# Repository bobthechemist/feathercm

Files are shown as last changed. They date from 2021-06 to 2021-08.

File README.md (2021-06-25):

# feathercm
Platform for learning about scientific instrumentation

## Test bed
A test of github desktop and atom integration

## Documentation


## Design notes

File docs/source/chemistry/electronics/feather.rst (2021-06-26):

What is a Feather?
==================

From the `Adafruit <https://www.adafruit.com/category/943>`_ website:

  Feather is a flexible and powerful family of microcontroller main-boards (Feathers) and daughter-boards (Wings) with a wide range of capabilities. They can be plugged into a breadboard for quick prototyping, have built-in battery connectors for your on-the-go projects, and most have built-in lipoly chargers!

We use the Feather platform because it's cheap, powerful and flexible.

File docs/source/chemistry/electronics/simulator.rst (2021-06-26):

Circuit simulator
=================

This circuit simulator can be found at www.falstad.com

.. raw:: html

  <iframe width='100%' height=500 src='https://www.falstad.com/circuit/circuitjs.html' frameborder='0'></iframe>

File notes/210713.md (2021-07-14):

https://book.pythontips.com/en/latest/ternary_operators.html might be an interesting template for book writing on the web.

Noise out of 6004A is fairly significant relative to what's coming from A0.  Adding a 105 cap across the feedback resistor reduces noise with a bit of change in the slope at 2 V.  Upon closer look, adding a cap doesn't improve the noise enough for me to bother, I think.  Might include an open space.

A number of updates to data and echem.  Confirmed that manual iR correction is working.  Can clean up CVs a bit with lowpassfiltering of the data (so post processing).  Added indicator light so user knows when CV scan is complete.  Added command to adjust C2V resistor value.

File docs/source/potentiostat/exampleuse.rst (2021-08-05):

.. _exampleuse:

Current operation
=================

Experimental setup
~~~~~~~~~~~~~~~~~~

Here's an overview of the potentiostat Featherwing,  bob173-beta\ [*]_, connected to an electrochemical cell.

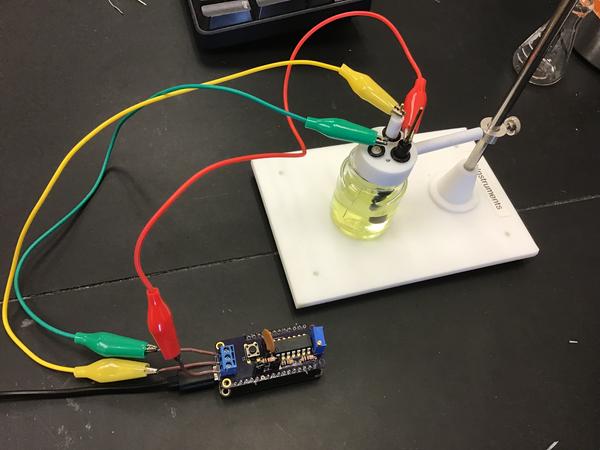
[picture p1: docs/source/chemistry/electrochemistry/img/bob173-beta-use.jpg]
The bob173-beta featherwing potentiostat


Details on the design are provided elsewhere and this page will focus on some example usage.  The setup is a 2 mm Pt disk working electrode with a Pt wire counter and Ag/AgCl reference.  The solution is 4.81 mM potassium ferrocyanide in 0.10 M potassium chloride.  The beta version of the board is pictured; however the gamma version was used for data collection.

Communication via python
~~~~~~~~~~~~~~~~~~~~~~~~

All FeAtHEr-Cm instrumentation will communicate with the user via the serial console interface.  The *easiest* way to do this is with a terminal  program such as `PuTTY <www.putty.org>`_ but the main limitation with that approach is the ease with which experimental data can be transferred.  Therefore, the next best approach is to interact with Python.  In addition to the standard Python installation (I'm using 3.9.6), the serial communication module needs to be installed with `pip install pyserial`.  Then, communication can be streamlined with the (to be documented) module `client.py`.  In a python shell, one would type:

.. code:: python

  >>> import client
  >>> f = client.fc('COM5')
  >>> f.send('get')
  >>> f.read()

The user sends commands using `f.send` and then reads the result using `f.read()`.  It's a primitive strategy at present but the approach will allow for much flexibility, since many systems and programming languages are capable of communicating in this fashion.  The potentiostat understands how to get and set the scan rate, potential limits and sampling frequency.  It also needs to know the value of the resistor in the current to voltage converter.

.. code:: python

  >>> f.send('set SR 0.8')
  >>> f.send('set SP -0.4')
  >>> f.send('set SW 0.6')
  >>> f.send('set EN -0.4')
  >>> f.send('current 9080')
  >>> f.send('go')

The last command tells the potentiostat to perform the cyclic voltammogram.  The user needs to know how long the experiment will take because it is possible to read from the serial buffer before it is populated with the data.  On the gamma version of the board, a red LED is lit when a CV scan is in process.

.. code: python

  >> data = f.read(1)
  >> f.save('myfile.csv', data)

The `1` in the read command above tells the client software to strip text and format numbers for easy export (via `save`) to a CSV file. These CSV files can then be processed the same way you'd process any other data.

Example data
~~~~~~~~~~~~

Figure of example data

  CV of ferrocyanide, 0.5 V/s, 2 mm Pt diameter electrode.  Anodic current is positive. Post processing (low-pass filter) performed in Mathematica.

Above is an example cyclic voltammogram obtained on the bob173-gamma.  The bob173 allows (rather, requires) the end user to manually select an appropriate resistor for the current to voltage conversion.  In this case, the resistor is nominally 2 kOhm, which results in fairly noisy data.  The peak current (~ 80 uA) corresponds to a voltage of 170 mV with this level of amplification, which is roughly 10% of the full scale (+/- 1.65 V) of the potentiostat.

Comparison of current-to-voltage converter setups

  CVs at 0.5 V/s with two separate current-to-voltage resistor values.

As shown above, switching the resistor value in the current-to-voltage converter should have no impact on the overall shape and magnitude of the cyclic voltammogram so long as the resistance does not result in overloading the amplifier.  Switching to a nominally 10 kOhm resistor results in a maximum voltage output of 730 mV.  The noise in the CV with greater amplification is noticeably reduced.  Note that when setting the current value, the measured resistance was used instead of the stated resistance (e.g. 9080 Ohm instead of 10 kOhm).  The resistors used in this setup have a reported tolerance of 5%; therefore, it is important to use the actual resistance.  Nonetheless, it can be seen that the 10 kOhm resistor results in a slightly larger current than the 2 kOhm resistor, suggesting that one (or both) of the resistor values are slightly incorrect.  The percent difference between the two peak currents is 7%.

Various scan rates of ferrocyanide

  Example of cyclic voltammograms from 10 mV/s to 10 V/s.  All voltammograms have been post processed with a low pass filter.

The figure above demonstrates the range of scan rates possible with the bob173-gamma.  After setting the current-to-voltage resistors properly (the lowest value used is 2 kOhm and the largest is 22 kOhm), scan rates between 10 mV/s and 10 V/s can be achieved.  At the highest scan rates, sampling frequency becomes a limiting factor.  The maximum sampling frequency is estimated to be 500 Hz and at 10 V/s with the potential range chosen here, the number of points in the CV is 48.  At the lower end of the scan-rate range, the issue is memory allocation.  Frequently, the low scan-rate scans fail with a memory allocation error.  This issue is likely a bug in the code and the current workaround is to lower the total number of points collected in a single CV scan.

.. note:: The bob173-gamma does have an option for iR compensation; however, it was not tested in this set of data.

Example workup
~~~~~~~~~~~~~~

Standard analysis of electrochemical data (workup) consists of exploring the change in peak current with scan rate, the increase in forward/reverse peak separations with scan rate, and the ratio of forward/reverse peak current as a function of scan rate.  Combined, these three analyses provide a general overview of the electrochemical system and allows for preliminary assignment of electron-transfer mechanisms and rates.

The average of the forward and reverse peak potentials is the :math:`E_{1/2}` relative to the reference electrode used.  This potential should stay constant throughout the range of scan rates employed for a redox system uncomplicated by additional chemical reactions.  The average potential for these data is :math:`0.250 \pm 0.004 V` vs Ag/AgCl which is in reasonable agreement with other reports.\ [*]_

diffusion control plot

  Peak current as a function of the square root of scan rate.  Red line is the best fit line through the data collected at scan rates below 1 V/s.

Above is a plot of the forward (anodic) peak current as a function of scan rate.  At scan rates below 1 V/s, the plot is linear, as expected from theory.  The deviation from linearity at higher scan rates could be due to ohmic drop, but it cannot yet be ruled out that instrumental factors such as sampling frequency and incorrect current-to-voltage settings are contributing factors.  Nonetheless, the lower scan rate data can be fit to the Randles-Sevcik equation in order to extract an estimate of the diffusion coefficient.

.. math::

    i_p = 2.69\times 10^5 n^\frac{3}{2} A C \sqrt{D \nu}

In the equation above, :math:`i_p` is the peak current, n is the number of electrons in the redox process, A is the electrode area in square cm, C is the concentration in mol/mL, D is the diffusion coefficient in cm/s and :math:`\nu` is the scan rate in V/s.  For the ferrocyanide data collected here, the best fit line through the low scan rate data has a slope of :math:`120\ \mu A s^{1/2} V^{-1/2}` which corresponds to a diffusion coefficient of :math:`8.7 \times 10^{-6}\ cm/s`. The reported value for the diffusion coefficient of ferrocyanide in potassium chloride is :math:`6.7 \times 10^{-6}\ cm/s`.\ [*]_ The error is reasonable given that the electrode diameter in this experiment is only known to the nearest mm.  The experimental error (30%) is much larger than what can be attributed to the estimated errors associated with the current-to-voltage conversion (7%) or the lack of temperature control (< 1 %).

The oxidation of potassium ferrocyanide is generally considered fast, and therefore the separation between the forward and reverse peaks should be approximately 59 mV and remain independent of scan rate.\ [*]_ In the figure below, :math:`\Delta E_p` is plotted as a function of scan rate up to 1 V/s.  At very low scan rates, the peak separation is independent of scan rate and approximately 72 mV.  As the scan rate increases, so does the :math:`\Delta E_p` in a non-linear fashion.  It is likely that ohmic losses are playing a role in the peak separation increase.

Analysis of electrochemical reversibility (and resistance)

  Forward/reverse peak separation (:math:`\Delta E_p`) as a function of scan rate.

Lastly, the ratio of the reverse and forward peak currents provides insight into the chemical reversibility of the electron-transfer process.  Both ferro- and ferricyanide are chemically stable under the conditions used in this experiment, so it is expected that the peak current ratio would be close to 1 and independent of scan rate.  Using Nicholson's empirical method for assessing chemical reversibility requires the current at the switching potential.

.. math::

    \frac{i_{rev}}{i_{fwd}} = \frac{i_{rev}}{i_{fwd}} + 0.48 \times \frac{i_{switch}}{i_{fwd}} + 0.086

The peak ratio for the entire scan rate regime investigated here is :math:`0.972 \pm 0.02`, which is expected.  Note that due to the way data are acquired by the bob173, the sampling frequency may "miss" the switching potential.  upon close inspection of the raw data, the recorded data point closest to the switching potential was on average 3 mV less than the target value.

Discussion
~~~~~~~~~~

The results presented here demonstrate the ability to acquire electrochemical data on an ideal redox system with sufficient quality to perform standard analyses such as estimates of the diffusion coefficient and assessment of the chemical and electrochemical reversibility of the redox system.  Post processing of the data is required due to limitations in the analog to digital (ADC) circuitry of the microcontroller used (the M4 Express) as well as the absence of any hardware based noise reduction strategies.  While it would be possibile to eliminate these issues through additional hardware, it would defeat the pedagogical and price-point objectives of the project.  Presently, the bob173-gamma can be created for under $30.  The only additional components not considered in that price are a USB cable and a computer with a USB connection capable of running Python.  A Raspberry Pi computer can be purchased for under $100 (including power and SD card storage but *not* considering keyboard/mouse/monitor peripherals) which is capable of controlling the bob173 via Python as well as perform the post-processing/visualization using Mathematica.  Mathematica is not required for the rudimentary processing and visualization steps, which could also be completed in Python by expanding upon the client.py package.

Additionally, the bob-173 provides some key learning opportunities.  The three main points of understanding are: the design of a voltage divider and the need for buffering; adding signals together using an operational amplifier; and amplifying and converting current from a physical measurement into a voltage that can be read by a computer.  Completion of this module will include lesson plans that explore simulated (via the Falstad online circuit simulator) and hands-on (via the bob173) activities.

client.py
~~~~~~~~~

Here's the module run on the client computer to interface with a FeAtHEr-Cm instrument.

.. code:: python

  import serial
  import csv
  from time import sleep

  class fc():
      def __init__(self, *argv):
          self.s = serial.Serial(argv[0],11500,timeout=1)

      def send(self, cmd):
          self.s.write(f'{cmd}\n\r'.encode('utf-8'))

      def read(self, *argv):
          r = []
          while self.s.in_waiting:
          	r = self.s.readlines()
          if len(argv) > 0:
              r = clean(r)
          return r

      def dia(self, cmd, duration = 1):
          self.send(cmd)
          sleep(duration)
          return self.read()

  def clean(response):
      out = []
      for i in response:
          try:
              out += [ list(map(float,i.strip(b'][\r\n').split(b', '))) ]
          # Silently ignore non-numbers
          except ValueError:
              pass
      return out

  def save(filename, data):
      with open(filename, mode='w', newline='') as f:
          fw = csv.writer(f, delimiter=',')
          for i in data:
              fw.writerow(i)

.. rubric:: Footnotes

.. [*] The name is derived from the first potentiostat that I used as a graduate student at the University of Vermont: the PAR173 by Princeton Applied Research.  While you may think that I've named the Featherwing after myself, it is actually the acronym for Brockport Original Builds.

.. [*] Get this citation.

.. [*] See for example, `<https://www.asdlib.org/onlineArticles/elabware/kuwanaEC_lab/PDF-19-Experiment1.pdf>`_

.. [*] I do not have a good citation for the heterogeneous electron transfer rate of ferrocyanide.

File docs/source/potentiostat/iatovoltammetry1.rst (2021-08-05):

.. _voltagedivider:

The Voltage Divider
===================

In voltammetric measurements, one controls the potential of an electrode immersed in an electrolytic solution containing a redox-active species and observes the current.  In this exercise, you will develop an understanding of how to design an instrument that can perform this experiment.

Let's first look at one approach for setting a potential.  The circuit below is called a *voltage divider* and consists of a voltage source and two resistors.  Notice how the voltage measured in between the two resistors is exactly one half the input voltage of 5 V.

.. raw:: html

  <iframe width='100%' height='500' src='https://tinyurl.com/ygwgal3q' frameborder='0'></iframe>

  Explore this simulation by doing the following:

* Change the values of the resistors and observe how they impact the output voltage.  To make this exercise more manageable, limit your resistor choices so that the *sum* of the resistance remains 2k  (e.g. 500 and 1.5k, 250 and 1.75k).  Determine if the output potential is proportional to the top resistor or the bottom resistor.
* The simulator indicates the flow of current with yellow dots.  Placing the mouse over a component will reveal the current flowing through the object and may provide other information.  Mouse over the voltage source and note the power.  Power is calculated using the equation :math:`P = V \times I` with units of Watts (W).  Determine if the current and power change with changing the resistor values.
* Perform the same exploration but start with resistor values of 10k each.  When adjusting the resistor values, keep the total resistance equal to 20k.  Note similarities and differences in the output voltage, current and power.

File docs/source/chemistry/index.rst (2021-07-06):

The FeAtHEr-Cm Textbook
=======================

Roadmap for version 1.0
~~~~~~~~~~~~~~~~~~~~~~~

Initially, content is not going to be self-standing and will leverage other textbooks that adequately cover theory and pre-requisite material.  Texts such as Skoog's *Principles of Instrumental Analysis* and Harris' *Quantitative Chemical Analysis* are sufficiently ubiquitous that a student will likely have access to one or both of those texts.  Harvey's *Analytical Chemistry 2.1* provides adequate background material on chemical theory and is freely accessible.  These texts will be referenced when background material is necessary.  Rather than reinvent the wheel, there will be little attempt to cover material that is already available in Harvey's text, so once it becomes necessary to introduce content that is presented in one of the "closed" textbooks, the focus will be on expanding on where Harvey lets off.

Building and using a potentiostat
~~~~~~~~~~~~~~~~~~~~~~~~~~~~~~~~~

An instrumental approach to voltammetric measurements will center on the construction of a potentiostat, which requires a basic understanding of circuits involving resistors, capacitors and operational amplifiers.  Circuit analysis at the level of Kirchhoff's voltage/current laws is not necessary and will not be presented.  Coverage of operational amplifiers will be limited to the two ideal principles of op amps (no current draw from the inputs and the voltage difference between the inputs is zero).

The potentiostat used in this course is built with problem-based exploration as a foundational design principle.  Not only are we ignoring important electrical engineering design concepts (which are beyond the scope of this program), but the resulting potentiostat will allow individual components to be probed and analyzed.  For example, the components used to define a virtual ground are also used to introduce the concept of a voltage divider and explore why voltage dividers need to be buffered with an operational amplifer.

Lastly, there is an excellent circuit simulation package available on the internet that is incorporated into the text.  It allows for just-in-time exploration of concepts that are introduced and will allow students to compare actual results to theoretical results.

The expected student trajectory is as follows:

1. Electronics principles

  * Understand what a voltage divider is and how it is created using two resistors
  * Explore relationship between resistor magnitude, power consumed and output voltage
  * Analyze the effect of an external load on a voltage divider
  * Compare simulated and actual performance metrics with the bob173.

2. An overview of operational amplifiers and their utility

  * Understand that an operational amplifier can compare the relative values of the input voltages
  * Explore the role of op amps in buffering an input
  * Evaluate how performance of a real operation amplifier compares to the ideal behavior of drawing no current.
    - This section will likely be the first entry into (circuit) python programming.
  * Explore how operational amplifiers can add multiple inputs together.
  * Explore how operational amplifiers can magnify the intensity of a signal.

3. Combining the elements - a basic adder potentiostat

  * Learn how to read a schematic
  * Explore python programming needed to communicate with the bob173
  * Calibrate voltage and current scales of the bob173
  * Perform a cyclic voltammetry experiment and analyze results

4. Going further - improving the potentiostat

  * Reducing noise
  * Incorporating iR compensation
  * Exploring instrument limitations
  * Exploring a "new" chemical system.

Building a colorimeter
~~~~~~~~~~~~~~~~~~~~~~

One of the most prevalent instrument design activities is the construction of a rudimentary spectrometer.  Rather than provide yet another example, the proposed instrument design activities will focus on several under-represented concepts:

* Exploring how an instrument controls/operates a source and records information from a detector
* Analyze non-idealities due to instrument design (a primary example is stray light)
* Investigating signal transduction for novel data acquisition strategies (one example might be transducing detector response to an audio signal)

One design idea is to intentionally incorporate source flicker into the instrument.  Then create a system that provides dual-beam capabilities and explore how effective this approach is at reducing such noise.

Concepts covered in this module will include electronics (transimpedance amplifiers), programming (digital and analog IO), deviations from Beer's Law and signal transduction.  It may also be an interesting segue into 3D printing design.

Building a thermal conductivity detector
~~~~~~~~~~~~~~~~~~~~~~~~~~~~~~~~~~~~~~~~

Prior to exploring chromatography instrumentation, we need to have a reasonable detector.  It is possible that one could use concepts in the previous sections (spectroscopy, voltammetry) to design a detector, and that could/should be part of a future direction.  Here we are interested in exploring a detector that is often described in instrumental analysis courses, the thermal conductivity detector.  Designing and testing the detector will provide an opportunity to further develop our electronics understanding through the development of a Wheatstone bridge.  The goal would be to develop an instrument that can, for example, analyze a binary gas sample.  The approach we are revisiting was first described in J. Chem Ed. 28, 576 (1951) and it is time we revisit this approach.

Creating a rudimentary Gas Chromatograph
~~~~~~~~~~~~~~~~~~~~~~~~~~~~~~~~~~~~~~~~

The previous module presented an approach to analyzing gaseous mixtures, which suggests that by adding a means to separate mixtures prior to TCD analysis should result in a functioning GC.  There are DIY GC designs on the internet that use packed columns (one of them actually uses kitty litter) which might be sufficient to perform alcohol separations.

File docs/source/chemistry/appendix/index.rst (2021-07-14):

Appendix
========

Various topics for just in time learning

* microcontroller basics
* essentials of resistor circuits
* python basics
* [Do][Explore][Act]
* Contributing
*

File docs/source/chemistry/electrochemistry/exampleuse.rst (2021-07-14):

Current operation
=================

Experimental setup
~~~~~~~~~~~~~~~~~~

Here's an overview of the potentiostat Featherwing,  bob173-beta[*]_, connected to an electrochemical cell.

The bob173-beta featherwing potentiostat

Details on the design are provided elsewhere and this page will focus on some example usage.  The setup is a 2 mm Pt disk working electrode with a Pt wire counter and Ag/AgCl reference.  The solution is ~ 10 mM potassium ferrocyanide in 0.1 M potassium nitrate.

Communication via python
~~~~~~~~~~~~~~~~~~~~~~~~

All FeAtHEr-Cm instrumentation will communicate with the user via the serial console interface.  The *easiest* way to do this is with a terminal  program such as `PuTTY <www.putty.org>`_ but the main limitation with that approach is the ease with which experimental data can be transferred.  Therefore, the next best approach is to interact with Python.  In addition to the standard Python installation (I'm using 3.9.6), the serial communication module needs to be installed with `pip install pyserial`.  Then, communication can be streamlined with the (to be documented) module `client.py`.  In a python shell, one would type:

.. code:: python

  >>> import client
  >>> f = client.fc('COM5')
  >>> f.send('get')
  >>> f.read()

The user sends commands using `f.send` and then reads the result using `f.read()`.  It's a primitive strategy at present.  The potentiostat understands how to get and set the scan rate, potential limits and sampling frequency.

.. code:: python

  >>> f.send('set SR 0.8')
  >>> f.send('set SP -0.4')
  >>> f.send('set SW 0.6')
  >>> f.send('set EN -0.4')
  >>> f.send('go')

The last command tells the potentiostat to perform the cyclic voltammogram.  The user needs to know how long the experiment will take because it is possible to read from the serial buffer before it is populated with the data.

.. code: python

  >> data = f.read(1)
  >> f.save('myfile.csv', data)

The `1` in the read command above tells the client software to strip text and format numbers for easy export (via `save`) to a CSV file. These CSV files can then be processed the same way you'd process any other data.

Example data
~~~~~~~~~~~~

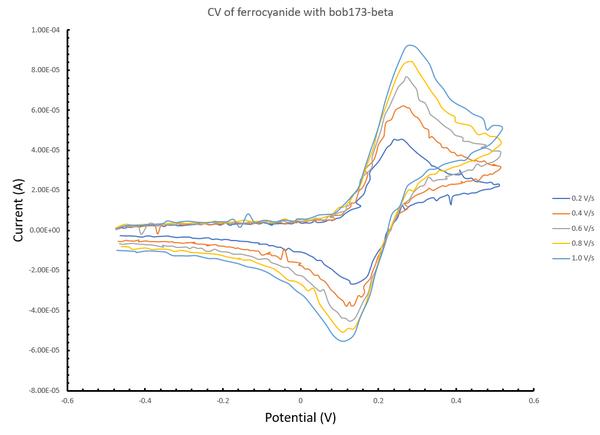
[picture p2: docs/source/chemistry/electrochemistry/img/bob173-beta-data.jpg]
Figure of example data


Above is a collection of cyclic voltammograms obtained on the bob173-beta.  The solution contains ferrocyanide and the data are plotted such that positive potentials are to the right and anodic current is positive[*]_. The scan rates range from 0.2 to 1.0 V/s and show the expected increase in current with increasing scan rate.  There is a fair amount of noise in the voltammograms.  The current amplification resistor in this version of the potentiostat is 15 kOhm which is appropriate for currents in the upper 10s of microamps.  Thus, I would expect decreased noise with a better choice of amplification resistor.  Further, there is no attempt to shield the potentiostat from EMF, which will likely also contribute noise.

Example workup
~~~~~~~~~~~~~~

A limited amount of analysis can be done at this stage.  First, one can confirm that the electrochemical process is diffusion controlled by plotting peak current as a function of the square root of scan rate.  The plot is reasonably linear with nonlinearities likely due to the aforementioned noise and to a lesser extent some issues with uncompensated resistance.  An important next step is to repeat this experiment with precise concentrations in order to verify that the diffusion coefficient estimated from these data is consistent with literature values.

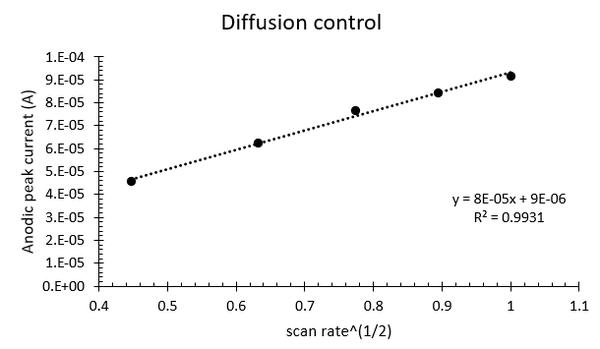
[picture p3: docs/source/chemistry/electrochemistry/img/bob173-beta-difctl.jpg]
Analysis of diffusion control


Chemical and electrochemical reversibility can be assessed by investigating the peak potentials and their currents.  Since the oxidation product, ferricyanide, is stable, it is expected that the ratio of the reverse to forward peak currents is close to one.  As calculated using the Nicholson equation, the ratio ranges from 0.91 to 0.95, which is a reasonable agreement given the rudimentary nature of the potentiostat.  Electrochemical reversibility is assessed by measuring the difference in peak potentials, as shown in the figure below.

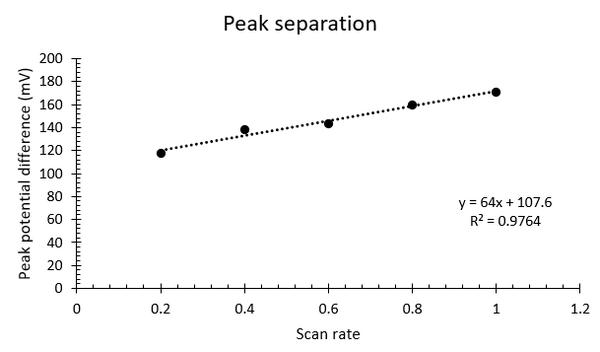
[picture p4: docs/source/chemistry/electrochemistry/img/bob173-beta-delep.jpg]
Analysis of electrochemical reversibility (and resistance)


At the slowest scan rates, the peak separation is approximately 120 mV, which is very large for this system and is likely influenced by uncompensated resistance.  The beta version of the potentiostat does not provide compensation.  While it is possible to incorporate the feature into a future design, it will be of limited use with the current platform since the microcontroller can only provide +/- 1.65 V and therefore will provide very little compliance.  That said, it is possible to improve the performance by using higher electrolyte concentrations and smaller electrodes.

Directions
~~~~~~~~~~

With this proof of concept data, we demonstrate that it is possible to perform electrochemical measurements with the bob173-beta featherwing.  The first area of improvement will be optimizing the current amplification stage and isolating the potentiostat from external interference.

client.py
~~~~~~~~~

Here's the module run on the client computer to interface with a FeAtHEr-Cm instrument.

.. code:: python

  import serial
  import csv
  from time import sleep

  class fc():
      def __init__(self, *argv):
          self.s = serial.Serial(argv[0],11500,timeout=1)

      def send(self, cmd):
          self.s.write(f'{cmd}\n\r'.encode('utf-8'))

      def read(self, *argv):
          r = []
          while self.s.in_waiting:
          	r = self.s.readlines()
          if len(argv) > 0:
              r = clean(r)
          return r

      def dia(self, cmd, duration = 1):
          self.send(cmd)
          sleep(duration)
          return self.read()

  def clean(response):
      out = []
      for i in response:
          try:
              out += [ list(map(float,i.strip(b'][\r\n').split(b', '))) ]
          # Silently ignore non-numbers
          except ValueError:
              pass
      return out

  def save(filename, data):
      with open(filename, mode='w', newline='') as f:
          fw = csv.writer(f, delimiter=',')
          for i in data:
              fw.writerow(i)

.. [*] The name is derived from the first potentiostat that I used as a graduate student at the University of Vermont: the PAR173 by Princeton Applied Research.  While you may think that I've named the Featherwing after myself, it is actually the acronym for Brockport Original Builds.
.. [*] Sorry Bill.

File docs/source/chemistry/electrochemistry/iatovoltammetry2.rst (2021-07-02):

Voltage Divider Problems
========================

.. note::

  In the last section, you should have noticed that the output voltage varies proportionally with the lower resistor and that the current and power are dependent on the sum of the two resistors. The equation for determining the output voltage is :math:`V_{out}=V_{in}\frac{R_{lower}}{R_{lower}+R_{upper}}`

One way we could create a variable potential is by changing the resistance values.  A variable resistor, or *potentiometer* provides this functionality.  The circuit below is similar to the one on the previous page, with several important differences:

* The two resistors are replaced by a potentiometer, which makes it easy to adjust the resistances above and below the test point while keeping the total resistance the same.  You should see a slider on the right hand side of the simulator that will control the potentiometer position.
* A switch has been added, which can be opened and closed with a double click.
* A new resistor has been added, which is the *load* or the object that we want to apply the output voltage to.

.. raw:: html

  <iframe width='100%' height='500' src='https://tinyurl.com/yfeq6ato' frameborder='0'></iframe>

Explore this simulation by doing the following:

* Make sure the switch is open.  Adjust the potentiometer so that the resistances are roughly equal and the output voltage is about 2.5 V.
* Close the switch and note how the output voltage is affected.  Collect several data points with varying the resistance and noting the lower resistor value, the output potential with the switch open and the output potential with the switch closed.

.. note::

  Notice how the load is in parallel with the lower resistor.  Since resistors in parallel add as inverses (:math:`\frac{1}{R_{total}}=\frac{1}{R_a}+\frac{1}{R_b}`), the load strongly impacts the performance of the voltage divider.  The load resistance must be much higher than the resistors used in the voltage divider in order to minimize this impact.

  However, using too small of a resistor for the voltage divider will result in excessive power usage.  One cannot optimize both low power consumption and load resistance tolerance.

Problems
~~~~~~~~

#. For a voltage divider with a total resistance of 2 kOhm, what is the minimum load resistance that will have a small (< 5%) impact on the desired output voltage?  (Assume for this exercise that Vout is 1/2 Vmax.)
#. Perform the same calculation for a 20 kOhm voltage divider.
#. Does the R95 (my term) change with changing the desired output voltage?

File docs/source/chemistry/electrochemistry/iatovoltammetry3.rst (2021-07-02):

An operational amplifier primer
===============================

.. note::

  We saw in the last section that the load we are trying to work with impacts the performance of a resistor-based voltage divider.  Ideally, we need to isolate the voltage divider from the load.  In this section we will learn how a component called an *operational amplifier* can perform that task.

Just the facts
~~~~~~~~~~~~~~

As this material is designed for chemists who need to know (or want to know) some useful electronics, we will skip a lot of the theory behind operational amplifiers and focus on the two important features that make them useful and then move on to several basic configurations that are found frequently in scientific instrumentation.

An operational amplifier is an active component that amplifies weak signals.  It has two inputs (a non-inverting input designated **+** and an inverting input designated **-**) and one output.  The symbol used for operational amplifiers in schematics is a triangle.

.. raw:: html

  <iframe width='100%' height='500' src='https://tinyurl.com/ydptekz5' frameborder='0'></iframe>

Note that in the diagram above, a square wave pulse with amplitude +/- 5 V is applied to the inverting input and the non-inverting input is tied to ground.  Try the following explorations:

* Describe the output in relation to the input
* Mouse over the oscilloscope trace to find the amplitude of the output signal.  Where does this value come from? (Hint: right click on the op amp and select properties.)
* Reconfigure the inputs so that the output signal is in phase with the input signal.

In this circuit, the op amp is behaving as a *comparator*.  It is comparing the two inputs and responding with the following result

* If the inverting input is greater than the non-inverting input (which is tied to ground) then set the output as negative as possible.
* If the inverting input is less than the non-inverting input, then set the output as positive as possible.

A comparator does one more thing, which isn't readily apparent in the simulation: if the inputs are equal, set the output to zero.

.. note::

  You should be able to give this a try by deleting the ground and adding a wire from the square wave source to the non-inverting input.

Two important points
~~~~~~~~~~~~~~~~~~~~

We'll quickly see that op amps can do much more than just compare the values of their inputs.  As we explore some other configurations, there are two important rules that we must keep in mind:

1. An operational amplifier does everything in its power to make the *difference* between voltages at the inverting and non-inverting inputs be zero.
2. In an ideal operational amplifier, the inputs do not draw any current.

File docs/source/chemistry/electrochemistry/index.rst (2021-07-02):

Instrumental Approach to Voltammetry
====================================

In this three week module, you will learn about the electrochemical method called *cyclic voltammetry* by building an instrument that performs the technique: a *potentiostat*.  We are going to use an *instrumental approach* whereby the focus will be on how to create an instrument that does the experiment we want to perform.

.. toctree::
  :maxdepth: 2
  :hidden:

  iatovoltammetry1
  iatovoltammetry2
  iatovoltammetry3
  echempt1

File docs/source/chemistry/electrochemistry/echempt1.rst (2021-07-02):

A review of Voltammetry fundamentals
====================================

Much of this section is paraphrased from `David Harvey's Analytical Chemistry 2.1 text <https://chem.libretexts.org/Bookshelves/Analytical_Chemistry/Book%3A_Analytical_Chemistry_2.1_(Harvey)/11%3A_Electrochemical_Methods>`_ which can be accessed via Libre Text.

.. seealso:: Be sure to check out section 11.1 of Harvey's book for a refresher on these topics. 

Electrochemical techniques rely on the measurement of potential and current in order to understand chemical phenomena such as reactivity and concentration.  Most, but not all, electrochemical techniques involve the study of the movement of electrons in an oxidation-reduction reaction.  There are several important concepts in electrochemistry which are worth reviewing:

#. we cannot control simultaneously current and potential
#. the electrode's potential determines the analyte's form at the electrode's surface
#. the concentration of analyte at the electrode's surface may not be the same as its concentration in bulk solution
#. current is a measure of the rate of the analyte's oxidation or reduction
#. in addition to an oxidation-reduction reaction, the analyte may participate in other chemical reactions

Let's discuss how these five concepts are incorporated into voltammetry.  The first item suggests that we must choose whether to control potential or current.  As the name suggests, we *measure* the current (-ammetry) as a function of potential in a voltammetric measurement. Because we control the potential, we control what is happening at the electrode surface.  We can adjust the potential to force a species in solution [#]_ to become oxidized or reduced by adjusting the potential relative to the reduction potential of the solute.  Note that we only have control of what happens *at the electrode/electrolyte interface*.  The bulk of the solution is unaffected unless we have specifically designed the experiment to influence the entire solution.  The fact that electrochemical reactions are happening *heterogeneously* in the solution has a significant impact on the relationships between current and potential that we will observe.  The last two points are what make voltammetry interesting.  Since current is a measure of the flow of electrons, more electron flow indicates that more oxidation or reduction (collectively, electrolysis) is happening.  Therefore, the magnitude of the current informs us about the rate of a reaction.  Lastly, we can use voltammetry to explore what - if anything - a molecule does before or after electrolysis.

.. rubric:: Footnotes

.. [#] technically, or adsorbed onto the electrode surface, but we won't deal with adsorbed species here.

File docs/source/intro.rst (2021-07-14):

Start Here
==========

**Welcome**. If you are here, you were either invited or spend an awful lot of time randomly clicking links on the internet...

``FeAtHEr-Cm`` is a platform for building a better understanding of scientific instrumentation.  It is my attempt at developing what I call an *Instrumental Approach to Chemical Analysis.*\ [*]_  Traditionally, the second semester of analytical chemistry covers instrumentation used in the discipline.  Recent advances in technology, electronics and programming allow us to explore how scientific measurements are made by *designing our own instruments* and using them to explore chemical systems.  FeAtHEr-Cm helps us do that.

Why FeAtHEr-Cm?
~~~~~~~~~~~~~~~

When exploring platforms that could be useful for introducing chemists it scientific instrumentation design, I wanted something that was relatively inexpensive, easy to operate, established, and supported by a larger community.  The `feather platform <https://learn.adafruit.com/adafruit-feather>`_ by Adafruit Industries checks all of those boxes *plus* provides a cross-compatible platform with a vast array of tools already available.  The flexibility comes at a cost, however, and that is the array of choices that can be made is a bit overwhelming.  To bring some focus to the project, I have made two design decisions:

* The microcontroller board that will serve as the brains of any FeAtHEr-Cm instrument is the M4 Express and there is no intention to make activities compatible with other microcontrollers.
* All programming will be done in `Circuit Python <circuitpython.org>`_

The primary reason for selecting the M4 is that this microcontroller contains two 12-bit digital-to-analog outputs, which simplifies many designs (not least of which is the potentiostat).  The analog inputs are also 12 bit which is a very nice feature in education-based instrumentation.  By limiting software design to circuit python we not only decrease the programming learning curve (only one language is needed to control and communicate with the instrument) but it increases the accessibility of the instrument by being a plug and play option.  Note that a big downside to the M4 is that the analog to digital converter (ADC) isn't as good as it needs to be, which is why *the instrument you build is not suitable for research applications*.  There are tweaks made (and being made) to address the problems so that the potentiostat remains easy to build and configure while still serving as a meaningful learning platform.

As for that odd capitalization, it is something I've done for a long time.  I'm not alone and there are `many chemists <https://www.ionicviper.org/>`_ who do this.

Want to dive in?
****************

If you are excited about this project and want to start exploring right away, then I suggest purchasing an `M4 Feather <https://www.adafruit.com/product/3857>`_  along with Adafruit's `parts pal <https://www.adafruit.com/product/2975>`_.  That will give you nearly all the parts you need, and many that you'll find fun to play with.  The only additional components I suggest would be alligator clips and a quad op amp - the MCP6004 - which isn't sold by Adafruit but you can find it at other vendors.  I purchase from `Newark <newark.com>`_ but you might want to try `Digikey <digikey.com>`_ as they are also a reseller for Adafruit products and you might be able to get all of the components from one vendor.

A work in progress
~~~~~~~~~~~~~~~~~~

This project is in the very early stages of development.  If you are visiting, you will likely find links that do not work, documentation that seems to require a significant amount of prerequisite knowledge, and many, many outlines and placeholders.  My intention for a *version 1.0* of this project is an instrument with activities for each of the three main areas of chemical instrumentation (spectroscopy, electrochemistry and chromatography).  I am currently working on the electrochemistry modules.

An open, collaborative effort
~~~~~~~~~~~~~~~~~~~~~~~~~~~~~

I am building this project using `github <github.com>`_ and `read the docs <readthedocs.com>`_ for a few important reasons.

* Both platforms provide open access to the content, so that others may view, use and modify what is presented here
* Both platforms work nicely together, allowing me to generate both software and instructional content in one location and have it display in a pretty format without much input on my part.
* This approach allows community members to contribute to the project either as content generators or content reviewers.

I imagine that users of the content will find typographical and content errors and wish to propose corrections; others may have suggestions on how to better present content.  With Github, those users should be able to make those requests in a documented, public fashion.  If the changes are accepted, they get pushed immediately to the project.

What to explore right now
~~~~~~~~~~~~~~~~~~~~~~~~~

The current area of activity is building the potentiostat, creating software for controlling it and developing activities for exploring how a potentiostat is built and operated.  You will likely see the most changes in these pages over the next few weeks.

.. [*] Yes, this title is homage to Ewing's 1954 text and no, it is not at all suggestive that I am (or ever will be) comparable to Ewing as a scientist.

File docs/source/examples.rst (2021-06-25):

Examples
========

Installation/Usage:
*******************
I'll get there eventually

Some other example
******************
:math:`\alpha > \beta`

.. math::

    n_{\mathrm{offset}} = \sum_{k=0}^{N-1} s_k n_k

    \ce{H2O -> H2 + O2}

.. seealso:: this is a simple **seealso** note.

.. note:: This is a **note** box.

.. warning:: this is a warning to you.

.. sidebar:: Sidebar Title
    :subtitle: Optional Sidebar Subtitle

    Subsequent indented lines comprise
    the body of the sidebar, and are
    interpreted as body elements.

Really cool embed
*****************

Wouldn't it be nice if you could embed code for dynamic web-based textbooks?

.. raw:: html

  <iframe width='100%' height='300' src='https://rdrr.io/snippets/embed/' frameborder='0'></iframe>

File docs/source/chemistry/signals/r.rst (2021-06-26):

Try R here
==========

R is a scripting language designed to facilitate data processing and analysis. On this page, you can try writing R code.  Note that this page uses `rdrr <https://rdrr.io>`_ to interpret commands.  This service is provided for free and queuing a large class might take a while.

.. raw:: html

  <iframe width='100%' height='500' src='https://rdrr.io/snippets/embed/' frameborder='0'></iframe>

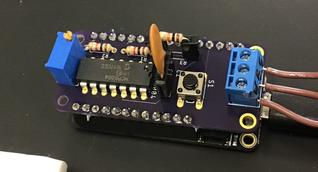
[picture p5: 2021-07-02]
docs/source/chemistry/electrochemistry/img/bob173-beta.jpg

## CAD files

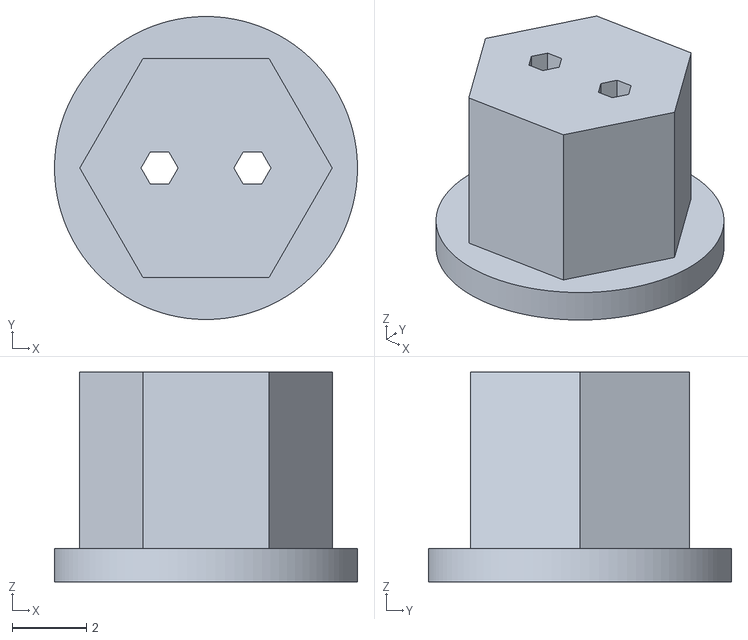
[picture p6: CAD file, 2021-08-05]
design/spectroscopy/turbidity-led-cap.stl
8.16 x 8.16 x 5.65

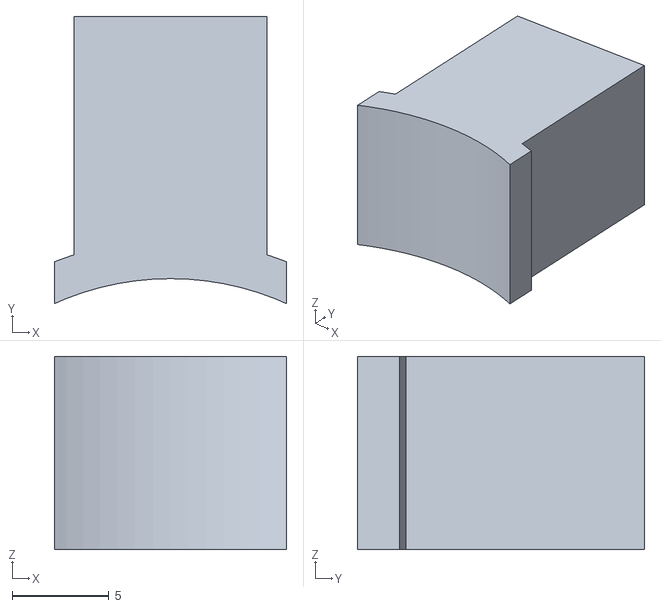
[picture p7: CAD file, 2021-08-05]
design/spectroscopy/turbidity-light-block.stl
12.0 x 14.9 x 10.0

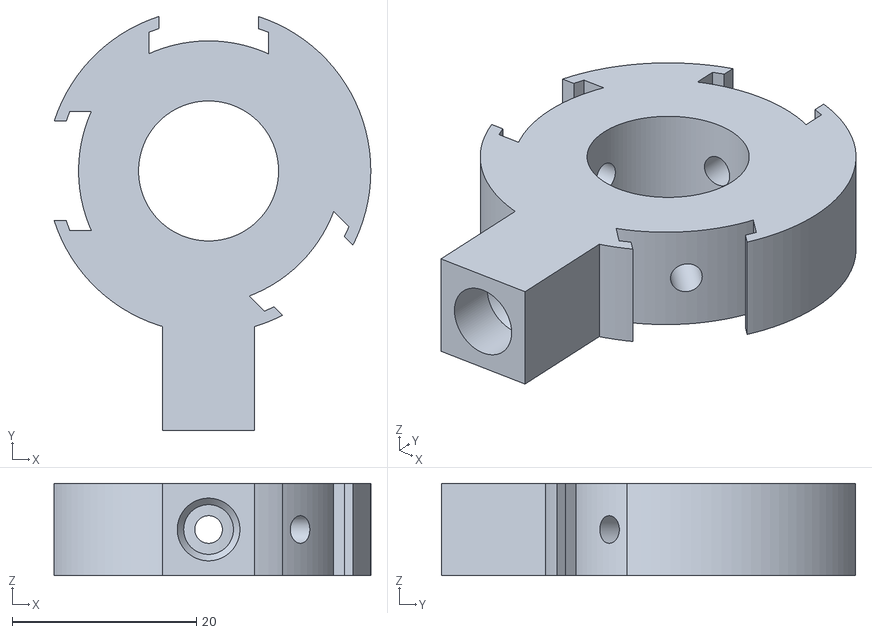
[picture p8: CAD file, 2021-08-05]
design/spectroscopy/turbidity-base.stl
34.4 x 45.0 x 10.0

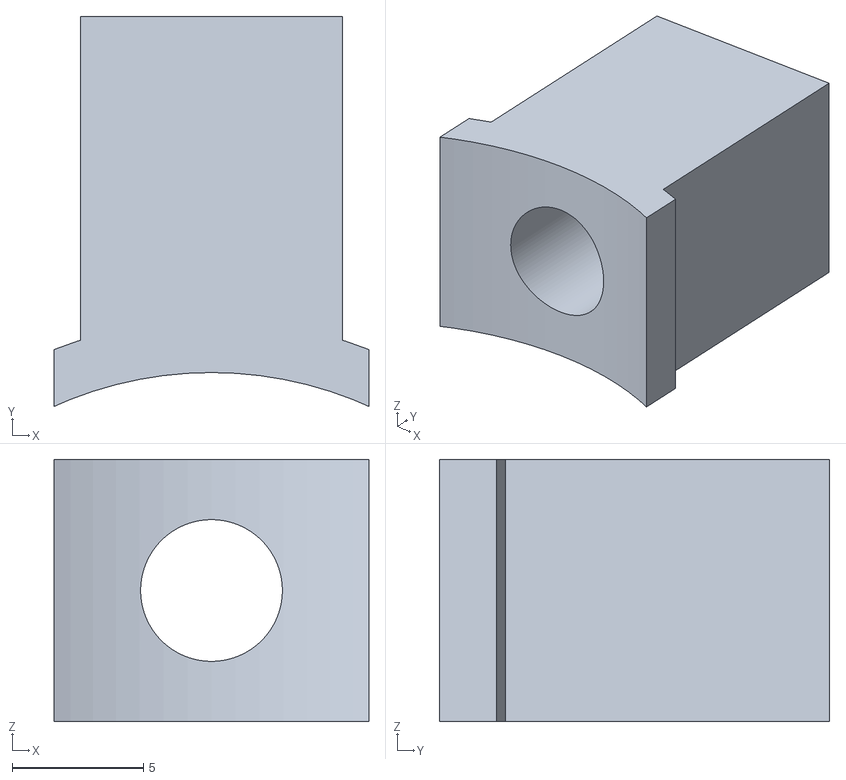
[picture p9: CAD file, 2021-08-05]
design/spectroscopy/turbidity-led-holder.stl
12.0 x 14.9 x 10.0

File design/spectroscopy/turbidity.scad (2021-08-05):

$fn=100;
/*
Block LED holder suitable for 5 mm LED.  Contains a stop for preventing LED from being inserted too far and is curved for a 40 degree arc.

210730- printed at 0.35 layer height, h1 is a tad small which prevents led from being inserted completely but provides some stability as it "snaps" into place.

Scaling 1.05 results in a very tight (one way) fit.  1.08 seems to work, as does a cell size of 7.6

Fixed source port to base since the sliders are too close together.

*/
r = 14.62; // Radius of device
w = 10; // length of chord (deprecated?)
h = 0.88; // height of arc ( deprecated?)
d1 = 6.8; // diameter of LED lip 
d2 = 5.4; // diameter of LED bulb
h1 = 5; // Arbitrary height for LED holder
h2 = 7.8; // height of LED bulb
hd = 1; // height for transition from d1 to d2
ht = h1 + h2 + hd + h;
zt = 10; // how tall the device is
xt = 12; // maximum width of LED holder
a = 112.5; // 90 + doc/2 where doc is degree of curvature
tol = 1; // Arbitrary for cleaner rendering
lipx = 1; // size of LED holder lip in x dimension
lipy = 2; // size of LED holder lip in y dimension
cell = 7.6; // sample holder diameter
sc = 1.08; // Empirical scaling to fit LED holder to base.

// Hole in the LED holder that securely holds the LED in place.  Unfortunately, a one size fits all approach isn't going to work, as different LEDs have slightly different lip diameters.
module cutout() {
    // Three cylinders on top of one another.  Larger diameter (d1) allows the lip of LED through.  It's height is arbitrary.  Transition from d1 to d2 probably only needed for rotated printing.  d2 and h2 are the height and diameter of the bulb.
    translate([0,0,zt/2])rotate(90,[1,0,0])translate([0,0,-ht/2])union(){
        translate([0,0,-tol])cylinder(d=d1,h=h1+tol);
        translate([0,0,h1])cylinder(d1=d1,d2=d2,h=hd);
        translate([0,0,h1+hd])cylinder(d=d2,h=h2+tol);
    }
}

// the LED holder consists of a solid block with a lip formed by subtracting two 
module block(){
    
    linear_extrude(zt)
    // center the final object
    translate([0,-r*sin(a)-ht/2])
    // disk with block protruding from it
    union(){
        difference(){
            translate([lipx-xt/2,r*sin(a)])square([xt-2*lipx,ht]);
            circle(r=r);
        }
    //Lip
    intersection(){
            translate([-xt/2,0])square([xt,3*ht]);
            difference(){
                circle(r=r+lipy);
                circle(r=r);
            }
        }
    }
}


module ledholder(){
    difference(){
        block();
        cutout();
    }    
}


// base contains a sample holder with diameter `cell` and radius `r`.  One LED holder is permanently fixed to the base as the source.  Three lips are extracted from the base at 180, 90 and 45 degres to allow for absorption and scattering measurements.
module base(){
    difference(){
        // Create circular base with one permanently fixed  LED holder.
        union(){
            linear_extrude(zt) circle(r=r+lipy+1);
            rotate(180,[0,0,1])translate([0,r*sin(a)+ht/2,0])ledholder();
        }
        union(){
            // Carve out sample holder 
            translate([0,0,-tol])cylinder(r=cell,h=zt+2*tol);
            // Carve out spaces for the LED holder lips
            for (i = [0,  90, 225]){
                rotate(i,[0,0,1])
                translate([0,r*sin(a)+ht/2,-tol])
                scale([sc,sc,1.2])block();
            }
            // Carve out holes for light
            for(i = [0,-90,180,45]){
                rotate(i,[0,0,1])
                translate([0,0,zt/2])
                rotate(90,[1,0,0])cylinder(d=3,h=2*r);
            }
        }
    }
}


// LED holder will need some way to secure the LED.  Make a compression fit cap.
module cap(){
    difference(){
        union(){
            // Cap top and hexagonal plug wtih same dimensions as the LED holder
            cylinder(d=1.2*d1,h=0.9);
            translate([0,0,0.9])
            cylinder(d=d1,h=0.95*h1,$fn=6);
        }
        for(i=[-1.25,1.25])
            // Carve out space for the LED legs
            translate([i,0,-tol])cylinder(d=1,h=2*h1,$fn=6);
    }
}
        


*cap();
*translate([0,ht+7,0])ledholder();
*base();
block();

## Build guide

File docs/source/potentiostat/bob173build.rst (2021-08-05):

.. _howtobuild:

Building the potentiostat
=========================

Introduction
~~~~~~~~~~~~

The potentiostat board is referred to as the `bob173` and is currently in `beta` form.  The design is based upon a potential control amplifier in the adder configuration which is described in full detail in Bard and Faulkner's Electrochemical Methods. [BARD2001]_ The main component for the potentiostat is a quad opamp (MCP6004).  To complete the package, there is a 20 kOhm potentiometer for creating a voltage divider (needed for establishing a virtual ground), a three-terminal wire-to-board connector, a push button, two 1 KOhm resistors, a 10 nF capacitor and a 15 kOhm resistor.  The schematic for the board is below:

Schematic for the bob173-gamma

  Schematic for the bob173-beta.  You can :download:`download the Eagle schamtic and board files here <bin/bob173-gamma-design-files.zip>`

The Eagle documents above can be used to create a layout that is compatible with the Featherwing format.  Details for creating your own boards are forthcoming, but the project can be completed without using a featherwing (although it will not be as compact).  In addition to a breadboard and some wires, you will need items listed in the table below.

.. csv-table:: Bill of Materials
  :header: "Part", "Value", "Package"

  CCV,"10 nF","C-US075-032X103"
  D11,"RST","TACT_PANA-EVQ"
  J1,"Electrodes","SCREWTERMINAL-3.5MM-3"
  MCP6004,"QUAD_OPAMPP","DIL14"
  MS1,"FEATHERWING","FEATHERWING"
  PIR,"20k","TRIM_US-RJ9W"
  PVG,"20k","TRIM_US-RJ9W"
  RA0,"1K","R-US_0204/7"
  RA1,"1K","R-US_0204/7"
  RCV,"10K","R-US_0204/7"
  RF,"1K","R-US_0204/7"
  RIR,"1K","R-US_0204/7"
  RLD,"1K","R-US_0204/7"
  RST,"RST","TACT_PANA-EVQ"

.. [BARD2001] Bard, Allen J., and Larry R. Faulkner. Electrochemical methods : fundamentals and applications. Hoboken, NJ: John Wiley & Sons, Inc, 2001. Print.

Operation notes
~~~~~~~~~~~~~~~

Using a terminal program or python to communicate with the FeAtHEr-Cm instrument.  Mathematica can also be used via the ExternalEvaluate command.

.. code:: mathematica

  (* start python session, send/receive data *)
  s = StartExternalSession["Python"]
  ExternalEvaluate[s, "s.write(b'cmd\\n\\r')"]
  o = ExternalEvaluate[s, "
  r = []
  while s.in_waiting:
    r = s.readlines()
  r"]
  (* Convert data to useable form, removing linefeeds *)
  p = FromCharactercode@DeleteCases[Normal@o,13|10,2]
  (* Convert list of number strings *)
  p2 = ImportString["["<>StringRiffle[Rest@p,","]<>"]","PythonExpression"]

Perhaps this is an easier approach

.. code:: mathematica

  (* Start the session, call it s, and execute the initial commands *)
  s = StartExternalSession["Python"],
  ExternalEvaluate[s, "import serial, s = serial.Serial('COM3', 115200, \
  timeout=1)"]
  (* Create an external evaluate shortcut *)
  ee[x_String] := ExternalEvaluate[s, x]
  (* Check if data are in the buffer *)
  ee["s.in_waiting"]
  (* Send a command *)
  ee@"s.write(b'get\\n\\r')"
  (* Simplify command construction *)
  st = StringTemplate["s.write(b'``\\n\\r')"],
  ee@st["get"]
  (* View the response *)
  FromCharacterCode@DeleteCases[Normal@#, 13 | 10, 2] &@ee@"
  r = []
  while s.in_waiting:
  	r = s.readlines()
  r
  "
  (* Make that a function *)
  res := FromCharacterCode@DeleteCases[Normal@#, 13 | 10, 2] &@ee@"
  r = []
  while s.in_waiting:
  	r = s.readlines()
  r
  "
  (* perform a sweep *)
  ee@st["go"]
  Pause[5]
  out = res
  (* A clunky way to conver the result *)
  vals = ImportString["[" <> StringRiffle[Rest@out, ","] <> "]",
    "PythonExpression"]

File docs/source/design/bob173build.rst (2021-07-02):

Building the potentiostat
=========================

Introduction
~~~~~~~~~~~~

The potentiostat board is referred to as the `bob173` and is currently in `beta` form.  The design is based upon a potential control amplifier in the adder configuration which is described in full detail in Bard and Faulkner's Electrochemical Methods. [BARD2001]_ The main component for the potentiostat is a quad opamp (MCP6004).  To complete the package, there is a 20 kOhm potentiometer for creating a voltage divider (needed for establishing a virtual ground), a three-terminal wire-to-board connector, a push button, two 1 KOhm resistors, a 10 nF capacitor and a 15 kOhm resistor.  The schematic for the board is below:

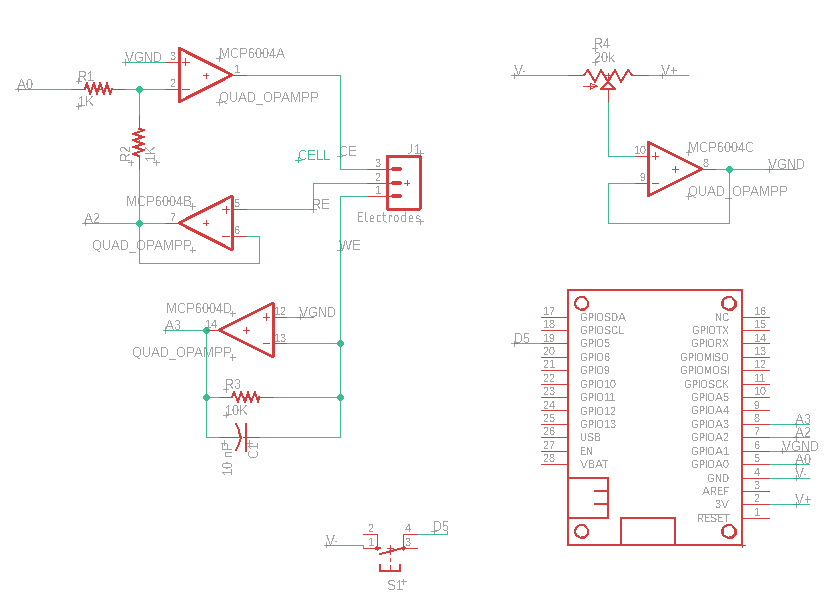
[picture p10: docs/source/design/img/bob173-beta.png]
Schematic for the bob173-beta


  Schematic for the bob173-beta.  You can :download:`download the Eagle schamtic and board files here <bin/bob173-beta-design-files.zip>`

The Eagle documents above can be used to create a layout that is compatible with the Featherwing format.  Details for creating your own boards are forthcoming, but the project can be completed without using a featherwing (although it will not be as compact).  In addition to a breadboard and some wires, you will need items listed in the table below.

.. csv-table:: Bill of Materials
  :header: "Part", "Value", "Package"

  "C1","10 nF","C-US050-025X075"
  "J1","Electrodes","SCREWTERMINAL-3.5MM-3"
  "MCP6004","QUAD_OPAMPP","DIL14"
  "MS1","FEATHERWING","FEATHERWING"
  "R1","1K","R-US_0204/7"
  "R2","1K","R-US_0204/7"
  "R3","10K","R-US_0204/7"
  "R4","20k","TRIM_US-RJ9W"
  "S1","N/A","B3F-10XX OMRON SWITCH"

.. [BARD2001] Bard, Allen J., and Larry R. Faulkner. Electrochemical methods : fundamentals and applications. Hoboken, NJ: John Wiley & Sons, Inc, 2001. Print.

Operation notes
~~~~~~~~~~~~~~~

Using a terminal program or python to communicate with the FeAtHEr-Cm instrument.  Mathematica can also be used via the ExternalEvaluate command.

.. code:: mathematica

  (* start python session, send/receive data *)
  s = StartExternalSession["Python"]
  ExternalEvaluate[s, "s.write(b'cmd\\n\\r')"]
  o = ExternalEvaluate[s, "
  r = []
  while s.in_waiting:
    r = s.readlines()
  r"]
  (* Convert data to useable form, removing linefeeds *)
  p = FromCharactercode@DeleteCases[Normal@o,13|10,2]
  (* Convert list of number strings *)
  p2 = ImportString["["<>StringRiffle[Rest@p,","]<>"]","PythonExpression"]

Perhaps this is an easier approach

.. code:: mathematica

  (* Start the session, call it s, and execute the initial commands *)
  s = StartExternalSession["Python"];
  ExternalEvaluate[s, "import serial; s = serial.Serial('COM3', 115200, \
  timeout=1)"]
  (* Create an external evaluate shortcut *)
  ee[x_String] := ExternalEvaluate[s, x]
  (* Check if data are in the buffer *)
  ee["s.in_waiting"]
  (* Send a command *)
  ee@"s.write(b'get\\n\\r')"
  (* Simplify command construction *)
  st = StringTemplate["s.write(b'``\\n\\r')"];
  ee@st["get"]
  (* View the response *)
  FromCharacterCode@DeleteCases[Normal@#, 13 | 10, 2] &@ee@"
  r = []
  while s.in_waiting:
  	r = s.readlines()
  r
  "
  (* Make that a function *)
  res := FromCharacterCode@DeleteCases[Normal@#, 13 | 10, 2] &@ee@"
  r = []
  while s.in_waiting:
  	r = s.readlines()
  r
  "
  (* perform a sweep *)
  ee@st["go"]
  Pause[5]
  out = res
  (* A clunky way to conver the result *)
  vals = ImportString["[" <> StringRiffle[Rest@out, ","] <> "]",
    "PythonExpression"]

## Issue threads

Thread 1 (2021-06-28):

How to do issue tracking

bobthechemist, 2021-06-28:
Is Github issue tracking a viable location for non-contributors to seek help?
Is issue tracking along with the project board a good way to manage the project/todo list?

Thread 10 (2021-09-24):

voltagedivider.rst

npadd1, 2021-09-24:
Section 1.4: "Create a spreadsheet with columns for the number of turns, output voltage and calculated upper/lower voltages."
Should this say upper/lower resistors?

bobthechemist, 2021-09-25:
(1) we only really need the lower voltage.  Is there a better way to phrase that?  What makes more sense when describing the two apparent resistors made in a potentiometer?

npadd1, 2021-09-27:
RESISTORS

bobthechemist, 2021-09-27:
Fixed with next push.

Closed 2021-09-27.

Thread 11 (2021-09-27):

voltagedivider.rst

npadd1, 2021-09-27:
"Voltage dividers cannot be used in bi-directional communication because it can only shift a voltage down. A 5 V source can be shifted down to 3.3 V, but a 3.3 V source cannot be shifted down to 5 V."

phrasing of this is unclear

bobthechemist, 2021-09-27:
Attempted to rephrase with:

>Voltage dividers **cannot** be used in bi-directional communication because it can only shift a voltage *down*.  A 5 V source can be shifted down to 3.3 V, but it does not make sense to shift a 3.3 V source *down* to 5 V.

npadd1, 2021-09-27:
That makes sense

Closed 2021-09-27.

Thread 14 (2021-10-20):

CV setting abreiviations

npadd1, 2021-10-20:
To change most of the CV settings the format used is 'set XX value' except to change the current to voltage resistor which is 'current value'. Could be changed to 'set CR value' for consistency.

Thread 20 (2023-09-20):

opamp.rst increase clarity of text.

bobthechemist, 2023-09-20:
Text in "you try":

>To understand the problem, change the simulation to have a Minimum voltage of 0 and a maximum voltage of 3.3. With a positive source voltage, is the output voltage the same as that predicted from the equations above? Is it possible to scale a negative voltage source?

Switch "simulation" to "operational amplifier" for clarity.

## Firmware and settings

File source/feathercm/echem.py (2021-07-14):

"""
feathercm.echem
~~~~~~~~~~~~~~~

This module contains functions and classes used in electrochemical measurements
"""
from .base import *
from .settings import *
from analogio import AnalogOut, AnalogIn
from digitalio import DigitalInOut, Direction
import time
import gc
from .data import data

class base:
    """Base class for electrochemical measurements
    """

    def __init__(self, control, voltage, current):
        """Settings are stored in a global config file (settings.py)
        """
        # TODO: Add error checking and default values
        self.controlPin = control
        self.controlActive = False
        self.control = None
        # I don't think we want the control pin to always be active
        #self.control = AnalogOut(control)
        self.voltage = AnalogIn(voltage)
        self.current = AnalogIn(current)
        # Use builtin for indicator
        self.led = DigitalInOut(board.D13)
        self.led.direction = Direction.OUTPUT


    def controlOn(self):
        if self.controlActive:
            raise(RuntimeError("Control pin already active. Bailing because this shouldn't happen."))
        else:
            try:
                self.control.deinit()
            except AttributeError:
                pass
            self.control = AnalogOut(self.controlPin)
            self.controlActive = True

    def controlOff(self):
        if not self.controlActive:
            raise(RuntimeError("Control pin is not active. Bailing because this shouldn't happen."))
        else:
            self.control.deinit()
            self.control = AnalogIn(self.controlPin)
            self.controlActive = False

    def scanrateCheck(self, scanrate):
        min = feathercmSettings["minimumScanrate"]
        max = feathercmSettings["maximumScanrate"]
        if not (scanrate >= min and scanrate <= max):
            raise(RuntimeError("{} is not a valid scan rate".format(scanrate)))

    def voltageCheck(self, voltage):
        mv = feathercmSettings["maxVoltage"]
        vg = feathercmSettings["virtualGround"]
        if not ( (voltage + vg) <= mv and (voltage + vg) ) >= 0:
            raise(RuntimeError("Voltage ({}) is out of range.".format(voltage)))

class sweep(base):
    def __init__(self,control, voltage, current):
        self.startPotential = -0.5 # Potentials in V
        self.switchPotential = 0.5
        self.endPotential = -0.5
        self.scanrate = 0.5 # V/s
        self.samplingFrequency = None
        self.setSamplingFrequency() # Hz
        self.ns = 10**9 # simple definition
        super().__init__(control, voltage, current)

    def setSamplingFrequency(self):
        '''Calculates the sampling frequency that results in 1024 points for the CV
        '''
        vt = abs(self.switchPotential - self.startPotential) + abs(self.endPotential - self.switchPotential)
        minval = feathercmSettings["minimumFrequency"]
        maxval = feathercmSettings["maximumFrequency"]
        numPoints = feathercmSettings["dataSize"]
        self.samplingFrequency =  min(maxval, max(minval,(numPoints * self.scanrate / vt)))


    def setParameter(self, param, value):
        # Parameter checks should go here. Not sure why I cannot use dict
        if param is "SR":
            self.scanrate = value
        elif param is "ST":
            self.startPotential = value
        elif param is "EN":
            self.endPotential = value
        elif param is "SW":
            self.switchPotential = value
        elif param is "SF":
            self.samplingFrequency = value
        else:
            raise NameError("Problem with parameter")


    def getParameter(self, param):
        params = {
            "SR": self.scanrate,
            "ST": self.startPotential,
            "EN": self.endPotential,
            "SW": self.switchPotential,
            "SF": self.samplingFrequency
        }
        if param in params:
            res = str(params[param])
        else:
            res = "NA"
        return res

    def doSweep(self):
        '''Next gen CV sweep
        '''
        # Inform user of sweep start
        self.led.value = True

        # clean up memory
        gc.collect()
        d = data("InvertedVoltage", "Current")
        self.controlOn()
        currPotential = self.startPotential
        analogWriteVoltage(self.control,currPotential)
        # Fixed quiet time
        time.sleep(0.5)
        lastPotlChange = 0
        lastCurrChange = 0
        initDirection = 1 if self.switchPotential > self.startPotential else -1
        tStart = time.monotonic_ns()
        tCurrent = tStart
        tSwitch = tStart + 10**9 * abs(self.startPotential - self.switchPotential)/self.scanrate
        tEnd = tSwitch + 10**9 * abs(self.endPotential - self.switchPotential)/self.scanrate
        doneQ = False
        potlDelta = 10**9/feathercmSettings["maximumFrequency"]
        self.setSamplingFrequency()
        currDelta = 10**9/self.samplingFrequency
        while not doneQ:
            if time.monotonic_ns() - lastPotlChange > potlDelta:
                # Change potential
                if time.monotonic_ns() < tSwitch:
                    currPotential = (time.monotonic_ns() - tStart)* \
                        initDirection*self.scanrate/10**9 + \
                        self.startPotential
                else:
                    currPotential = (time.monotonic_ns() - tSwitch)*(-1)* \
                        initDirection*self.scanrate/10**9 + self.switchPotential
                analogWriteVoltage(self.control, currPotential)
                lastPotlChange = time.monotonic_ns()
            if time.monotonic_ns() - lastCurrChange > currDelta:
                d.append([analogRead(self.voltage), analogRead(self.current)])
                lastCurrChange = time.monotonic_ns()
            doneQ = time.monotonic_ns() > tEnd
        # Turn off control
        self.controlOff()

        self.led.value = False

        return d




# Board module should identify itself
FEATHERWING = "echem"

# Functions needed for the board
def initFunc(*argv):
    global instrument
    instrument = sweep(board.A0, board.A2, board.A3)
    return f'I have initialized {argv[0]}'

def goFunc(*argv):
    global instrument
    out = instrument.doSweep()
    return out

def testFunc(*argv):
    time.sleep(5)
    return [1.2,2.4]

def setFunc(*argv):
    global instrument
    res = str(argv)
    if argv[0] is None:
        res = "Choose from scan rate (SR), start potential (ST), switch potential (SW), end potential (EN) or sampling frequency (SF)."
    else:
        # Split argument
        par = argv[0].split(" ", 1)
        if par[0] in ('SR', 'ST', 'SW', 'EN', 'SF'):
            res = f'I will set {par[0]} to {par[1]}.'
            instrument.setParameter(par[0],float(par[1]))
        else:
            res = f'{par[1]} Valid parameters are: SR, ST, SW, EN, and SF.'
    return res
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

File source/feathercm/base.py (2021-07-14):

import supervisor
import board
from .settings import *
from .data import data

# Base functions

def initFunc(*argv):
    '''Default initialization function

    Featherwing module should override this function, although it doesn't have to.
    '''
    return 'No Featherwing initialization function found.'

def rebootFunc(*argv):
    '''Reboots the potentiostat
    '''
    supervisor.reload()

commandList += ["init", "reboot"]
functionList += [initFunc, rebootFunc]


def init(featherwing):
    '''Starts feather-cm
    '''
    mergeDict(makeCommandDict(commandList, functionList))
    response = commandDict['init'](featherwing)
    respond(response)

def sba():
    '''Checks if a command is available on the serial line
    '''
    return supervisor.runtime.serial_bytes_available

def listen():
    '''Starts listening to the serial line

    If a command is present, read the line, check if it is a valid command, execute the command and return the response.
    '''
    global command, argument
    if sba():
        currentMessage = input().strip()
        parts = currentMessage.split(" ", 1)
        if len(parts) == 2:
            (command, argument) = parts
        else:
            command = parts[0]
            argument = None
        if commandValidQ():
            response = commandDict[command](argument)
        else:
            response = "Invalid command"
        respond(response)

def commandValidQ():
    '''Checks if the latest command is valid
    '''
    return command in commandDict.keys()

def respond(response):
    ''' Posts a response
    '''
    if type(response) is str:
        print(response)
    elif type(response) is data:
        for i in response.processData():
            print(i)
    elif type(response) is list:
        for i in response:
            print(i)
    else:
        print(f"I cannot handle type: {type(response)}.")

# Support functions

def analogWriteValue(x):
    '''Returns the 'correct' 12-bit integer value that generates the expected voltage
    for the input value.  To perform this calibration, measure the actual voltage (with DVM) at
    A0 with respect to A0 setting.  Best results are obtained for voltages under 2.0.  Find the
    absolute error and convert that to an A0 adjustment value. Find the best fit line between A0 (x axis)
    and A0 adjustment value (y axis).

    Note: the M4 cannot handle rail-to-rail and output is limited to 0.1 to 3.2
    '''
    slope = 1.005747
    intercept = 28.3129
    if x < intercept:
        raise ValueError(f"Analog output value must be greater than {intercept}.")
    elif not 124 <= x <= 3972:
        raise ValueError(f"Requested value is outside of the range possible with M4.")
    return int(x * slope - intercept)

def analogWrite(pin, value):
    '''Writes to an analog pin after correcting for calibration curve adjustments and switching
    value from 12 bit to 16 bit.
    '''
    val = analogWriteValue(value) << 4
    #print(f'sending {val}')
    pin.value = val
    return None

def analogWriteVoltage(pin, value, vground = True):
    '''Writes to an analog pin the requested voltage after correcting for calibration curve
    adjustments.  Will correct for virtual ground if requested.
    '''
    val = value
    if vground:
        val += feathercmSettings["virtualGround"]
    val = val/feathercmSettings["maxVoltage"] * 4096
    val = analogWriteValue(val)
    #print(f'sending {val}')
    pin.value = val << 4
    return None

def analogRead(pin, n = 8):
    ''' Reads an analog pin and adjusts the value according to a linear calibration.  Allows
    rapid signal averaging and returns the value as 12-bit.  Currently, errors seem to be on the
    order of +/- 5 mV.
    '''
    slope = 1.000405 # Consider putting calibration data in the settings file
    intercept = -12.7531
    val = 0
    for i in range(n):
        val += pin.value >> 4 # convert to 12-bit
    val = val/n
    return int(val * slope + intercept)

def toVoltage(reading, vground = True):
    '''Convert a 12-bit reading into a voltage.  Setting vground = False will return 0 to 3.3 V,
    a true value will return -1.65 to +1.65 V
    '''
    val = reading/4096 * feathercmSettings["maxVoltage"]
    if vground:
        val -= feathercmSettings["virtualGround"]

    return val

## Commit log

2021-07-01 First experiment with 0.1.0
    [sr0200.csv, sr0400.csv, sr0600.csv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]
2021-07-01 sample data analysis
    [dataproc.xlsx]
2021-07-02 Revert "sample data analysis"
    This reverts commit ff2f4b12a55e2d0133c979198ad5139433a2c4ec.
    [dataproc.xlsx]
2021-07-09 Added analog fix function
    [base.py]
2021-07-09 analogio
    Working on calibration and workarounds for ADC/DAC limitations.
    [base.py]
2021-08-05 spec-start init commit
    [turbidity-base.stl, turbidity-led-cap.stl, turbidity-led-holder.stl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]
